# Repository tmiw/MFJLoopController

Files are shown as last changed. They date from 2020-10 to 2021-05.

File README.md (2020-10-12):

# MFJLoopController
A ESP8266-based remote controller for MFJ magnetic loops.

## Prerequisites

* WEMOS D1 mini Lite development board (or clone). [Example](https://www.amazon.com/gp/product/B081PX9YFV/ref=ppx_yo_dt_b_asin_title_o03_s00?ie=UTF8&psc=1)
* [Adafruit ADS1115 ADC](https://www.adafruit.com/product/1085)
* Arduino IDE with ESP boards and [LittleFS data uploader tool](https://arduino-esp8266.readthedocs.io/en/latest/filesystem.html#uploading-files-to-file-system) installed
* [MFJ Bias Tee](https://mfjenterprises.com/products/mfj-4116)
* [H bridge circuit](http://www.modularcircuits.com/blog/articles/h-bridge-secrets/h-bridges-the-basics/) to produce +/- 12V. Initial tests done with [LED based solid state relays](https://www.mouser.com/ProductDetail/IXYS-Integrated-Circuits/LCC120?qs=TzJIIqIe2vmIthf%252BEZpoaA%3D%3D) linked together in series to reduce required pin count to 2 (one for each direction).
* Isolated power supply (e.g. **NOT** connected to radio's ground). [This Mouser project](https://www.mouser.com/ProjectManager/ProjectDetail.aspx?AccessID=d2ae561f5a) seems to work reasonably well in initial testing to permit sharing 12V power supply with rest of shack (see datasheets for the TMR 9-1212 for required support circuitry to reduce possible RFI).
* Soon: SWR bridge capable of reading 100W and providing 3.3V max analog signals to the ADS1115 ([possible option](https://en.golb.be/automatic-magnetic-loop-tuner-swr-bridge/))

## Setup

1. Set configuration options (pins, Wi-Fi info, etc.) in config.h.
2. Build and upload software using Arduino IDE to device. *Note: the initial upload must be done using USB or UART; subsequent uploads can be done OTA.*
3. Upload filesystem using Tools > ESP8266 LittleFS Data Upload in the Arduino IDE.

## Usage

By default, the software uses DHCP to get an IP address. Simply go to its assigned IP address on port 80 in a Web browser and click on the desired tuning direction buttons; releasing the associated button results in tuning stop. Note that you're looking for maximum signal/noise for the initial pass at tuning; the eventual auto-tune feature will perform fine tuning for minimal SWR.

## To Do

* Auto-tuning
* SSL support?
* PCB combining all hardware and eliminating loose wires

## License

BSD 3-clause (TBD)

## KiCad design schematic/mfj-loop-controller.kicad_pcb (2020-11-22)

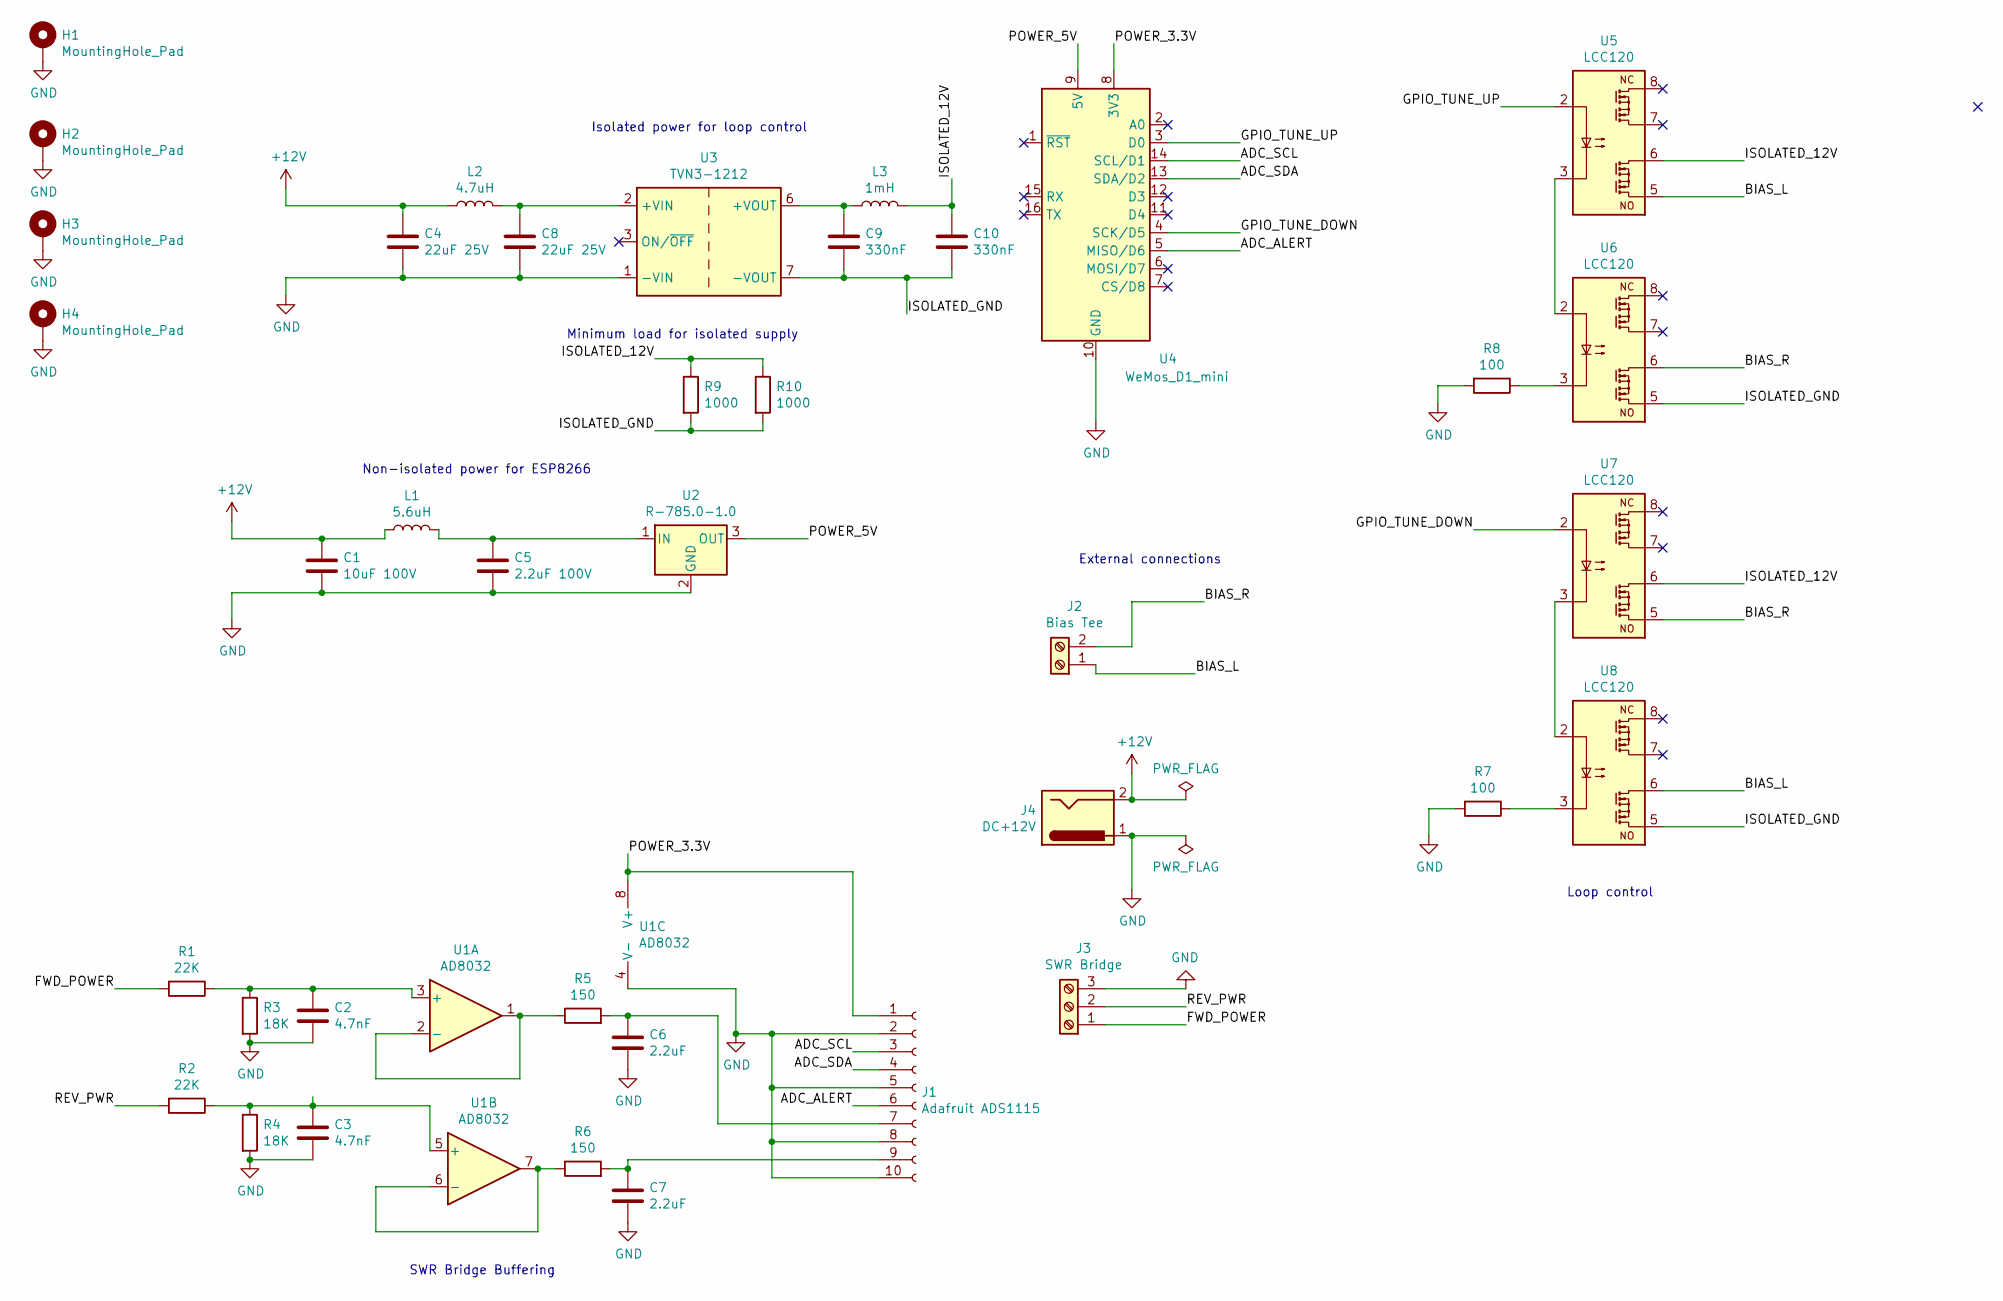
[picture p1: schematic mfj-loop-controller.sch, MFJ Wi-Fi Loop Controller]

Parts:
C1: 10uF 100V; C_Axial_L5.1mm_D3.1mm_P7.50mm_Horizontal
C2, C3: 4.7nF; C_Axial_L5.1mm_D3.1mm_P7.50mm_Horizontal
C4, C8: 22uF 25V; C_Axial_L5.1mm_D3.1mm_P7.50mm_Horizontal
C5: 2.2uF 100V; C_Axial_L5.1mm_D3.1mm_P7.50mm_Horizontal
C6, C7: 2.2uF; C_Axial_L5.1mm_D3.1mm_P7.50mm_Horizontal
C9, C10: 330nF; C_Axial_L5.1mm_D3.1mm_P7.50mm_Horizontal
H1, H2, H3, H4: MountingHole_Pad; MountingHole_3.2mm_M3_DIN965_Pad_TopBottom
J1: Adafruit ADS1115; PinHeader_1x10_P2.54mm_Vertical
J2: Bias Tee; TerminalBlock_bornier-2_P5.08mm
J3: SWR Bridge; TerminalBlock_bornier-3_P5.08mm
J4: DC+12V; BarrelJack_CUI_PJ-063AH_Horizontal_CircularHoles
L1: 5.6uH; L_Axial_L5.3mm_D2.2mm_P10.16mm_Horizontal_Vishay_IM-1
L2: 4.7uH; L_Axial_L5.3mm_D2.2mm_P10.16mm_Horizontal_Vishay_IM-1
L3: 1mH; L_Axial_L5.3mm_D2.2mm_P10.16mm_Horizontal_Vishay_IM-1
R1, R2: 22K; R_Axial_DIN0207_L6.3mm_D2.5mm_P10.16mm_Horizontal
R3, R4: 18K; R_Axial_DIN0207_L6.3mm_D2.5mm_P10.16mm_Horizontal
R5, R6: 150; R_Axial_DIN0207_L6.3mm_D2.5mm_P10.16mm_Horizontal
R7, R8: 100; R_Axial_DIN0207_L6.3mm_D2.5mm_P10.16mm_Horizontal
R9, R10: 1000; R_Axial_DIN0207_L6.3mm_D2.5mm_P10.16mm_Horizontal
U1: AD8032; DIP-8_W7.62mm_Socket
U2: R-785.0-1.0; Converter_DCDC_RECOM_R-78E-0.5_THT
U3: TVN3-1212; Converter_DCDC_TRACO_TMR-xxxx_THT
U4: WeMos_D1_mini; WEMOS_D1_mini_light
U5, U6, U7, U8: LCC120; DIP-8_W7.62mm_Socket

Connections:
+12V: C1.1, C4.1, J4.2, L1.1, L2.1
/ADC_ALERT: J1.6, U4.5 (MISO/D6)
/ADC_SCL: J1.3, U4.14 (SCL/D1)
/ADC_SDA: J1.4, U4.13 (SDA/D2)
/BIAS_L: J2.1, U5.5, U8.6
/BIAS_R: J2.2, U6.6, U7.5
/FWD_POWER: J3.1, R1.2
/GPIO_TUNE_DOWN: U4.4 (SCK/D5), U7.2
/GPIO_TUNE_UP: U4.3 (D0), U5.2
/ISOLATED_12V: C10.1, L3.2, R9.1, R10.1, U5.6, U7.6
/ISOLATED_GND: C9.2, C10.2, R9.2, R10.2, U3.7 (-VOUT), U6.5, U8.5
/POWER_3.3V: J1.1, U1.8 (V+), U4.8 (3V3)
/POWER_5V: U2.3 (OUT), U4.9 (5V)
/REV_PWR: J3.2, R2.2
GND: C1.2, C2.2, C3.2, C4.2, C5.2, C6.2, C7.2, C8.2, H1.1, H2.1, H3.1, H4.1, J1.2, J1.5, J1.8, J1.10, J3.3, J4.1, R3.2, R4.2, R7.2, R8.2, U1.4 (V-), U2.2 (GND), U3.1 (-VIN), U4.10 (GND)
unnamed: C2.1, R1.1, R3.1, U1.3 (+)
unnamed: C3.1, R2.1, R4.1, U1.5 (+)
unnamed: C5.1, L1.2, U2.1 (IN)
unnamed: C6.1, J1.7, R5.2
unnamed: C7.1, J1.9, R6.2
unnamed: C8.1, L2.2, U3.2 (+VIN)
unnamed: C9.1, L3.1, U3.6 (+VOUT)
unnamed: R5.1, U1.1, U1.2 (-)
unnamed: R6.1, U1.6 (-), U1.7
unnamed: R7.1, U8.3
unnamed: R8.1, U6.3
unnamed: U5.3, U6.2
unnamed: U7.3, U8.2

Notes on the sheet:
Minimum load for isolated supply
Isolated power for loop control
Non-isolated power for ESP8266
SWR Bridge Buffering
Loop control
External connections

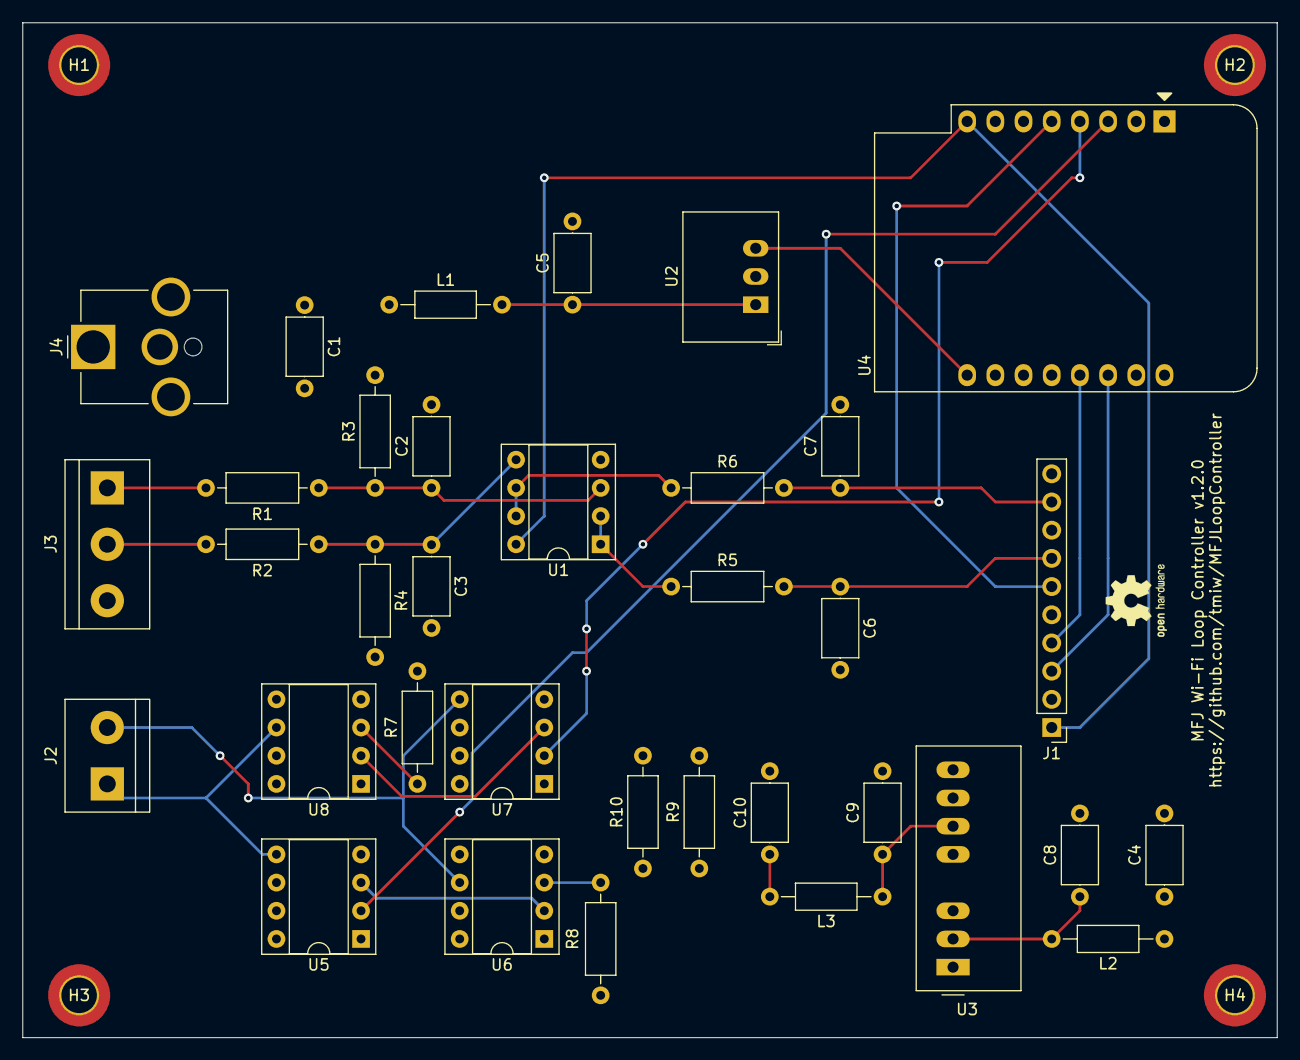
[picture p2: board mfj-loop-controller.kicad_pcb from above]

Board: 4 copper layers, 113.0 x 91.4 mm, 39 parts (0 on the bottom side), 28 nets.

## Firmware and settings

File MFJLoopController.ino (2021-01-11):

#include <ESP8266WiFi.h>
#include <WiFiClient.h>
#include <ArduinoOTA.h>
#include <LittleFS.h>
#include "WebServerController.h"
#include "CapacitorController.h"
#include "PowerMonitor.h"
#include "AutoTuneController.h"
#include "config.h"

CapacitorController capController;
PowerMonitor powerMonitor;
AutoTuneController autoTuneController(&capController, &powerMonitor);
WebServerController webServerController(&capController, &powerMonitor, &autoTuneController);

void checkWifi()
{
  if (WiFi.status() != WL_CONNECTED)
  {
    delay(1);
    
    WiFi.mode(WIFI_STA);
    WiFi.begin(STASSID, STAPSK);
  
    // Wait for connection
    while (WiFi.status() != WL_CONNECTED) {
      delay(500);
    }

    // Close all existing connections. If we disconnected, the connections are invalid anyway.
    webServerController.closeAll();
  }
}

void setup() {
  checkWifi();
  
  // FS init
  LittleFS.begin();
  
  capController.setup();
  powerMonitor.setup();
  webServerController.setup();
  autoTuneController.setup();
  
  // Set up OTA
  // Port defaults to 8266
  // ArduinoOTA.setPort(8266);

  // Hostname defaults to esp8266-[ChipID]
  // ArduinoOTA.setHostname("myesp8266");

  // No authentication by default
  // ArduinoOTA.setPassword("admin");

  ArduinoOTA.onStart([]() {
    // Stop what we're doing, if anything.
    capController.setDirection(CapacitorController::NONE);
    capController.setSpeed(CapacitorController::IDLE);
    capController.process();
    powerMonitor.enableAdc(false);

    // Wait a few ms for the ADC to stop signaling
    delay(5);
    
    String type;
    if (ArduinoOTA.getCommand() == U_FLASH) {
      type = "sketch";
    } else { // U_FS
      type = "filesystem";
      LittleFS.end();
    }
    
    //Serial.println("Start updating " + type);
  });
  ArduinoOTA.onEnd([]() {
    //Serial.println("\nEnd");

    // Remount FS
    LittleFS.begin();

    // Re-enable ADC
    powerMonitor.enableAdc(true);
  });
  ArduinoOTA.onProgress([](unsigned int progress, unsigned int total) {
    //Serial.printf("Progress: %u%%\r", (progress / (total / 100)));
  });
  ArduinoOTA.onError([](ota_error_t error) {
    //Serial.printf("Error[%u]: ", error);
    if (error == OTA_AUTH_ERROR) {
      //Serial.println("Auth Failed");
    } else if (error == OTA_BEGIN_ERROR) {
      //Serial.println("Begin Failed");
    } else if (error == OTA_CONNECT_ERROR) {
      //Serial.println("Connect Failed");
    } else if (error == OTA_RECEIVE_ERROR) {
      //Serial.println("Receive Failed");
    } else if (error == OTA_END_ERROR) {
      //Serial.println("End Failed");
    }
  });
  ArduinoOTA.begin();

}

void loop() 
{
  checkWifi();
  
  // Handle OTA
  ArduinoOTA.handle();

  capController.process();
  powerMonitor.process();
  autoTuneController.process();
  webServerController.process();
}

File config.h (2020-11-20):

#if !defined(CONFIG_H)
#define CONFIG_H

#include <ESP8266WiFi.h>

// Define STASSID (your wireless SSID) and STAPSK (your network's password)
// inside config-wifi.h. The below file is in .gitignore to prevent accidental check-in.
#include "config-wifi.h"

#define MDNS_NAME "mfj-loop"

#define TUNE_UP_PIN D0
#define TUNE_DOWN_PIN D5
#define ADC_INTERRUPT_PIN D6
#define TUNE_LED_PIN D4

// ADC gain
#define ADC_GAIN GAIN_ONE

// ADC channels
#define ADC_FWD_CH 0
#define ADC_REV_CH 2

// Fine tuning pulse time.
#define TUNE_FINE_PULSE_OFF_TIME_MS 150
#define TUNE_FINE_PULSE_ON_TIME_MS 18

// Slow tuning pulse time.
#define TUNE_SLOW_PULSE_OFF_TIME_MS 115
#define TUNE_SLOW_PULSE_ON_TIME_MS 36

// Fast tuning pulse time.
#define TUNE_FAST_PULSE_OFF_TIME_MS 0
#define TUNE_FAST_PULSE_ON_TIME_MS 36

// Minimum SWR difference (from prior reading) to wait for while in a wait state
// before proceeding to the next state.
#define AUTOTUNE_MIN_SWR_DIFF_IN_WAIT 0.1

// Length of time to move in the opposite direction before beginning auto-tune. This
// time is to ensure that we pass the dip while in fast mode (instead of stopping just
// short of it).
#define AUTOTUNE_BEGIN_TUNE_TIME_MS 2000

// VSWR "tuning complete" threshold (below after which we switch to slow tuning).
#define FAST_AUTOTUNE_COMPLETE_VSWR_THRESH ((double)2.0)

// VSWR "tuning complete" threshold (below after which we stop tuning).
#define SLOW_AUTOTUNE_COMPLETE_VSWR_THRESH ((double)2.0)

// Minimum wait time between tuning states to ensure capacitor remains stable enough
#define MIN_TUNE_WAIT_TIME_MS 100

// Maximum "good enough" SWR to exit tuning.
#define MAX_GOOD_SWR_END_TUNING ((double)1.5)

#endif // CONFIG_H

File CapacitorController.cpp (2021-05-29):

#include "CapacitorController.h"
#include "config.h"

CapacitorController::CapacitorController()
: direction_( NONE )
, speed_( IDLE )
, pwmState_( DISABLED )
, pwmPin_( 0 )
, pwmHighTimeMs_( 0 )
, pwmLowTimeMs_( 0 )
, pwmStateStartTime_( 0 )
{
  // empty
}

CapacitorController::~CapacitorController()
{
  // empty
}

void CapacitorController::setup()
{
  // Initialize both tuning pins to low.
  pinMode(TUNE_UP_PIN, OUTPUT);
  pinMode(TUNE_DOWN_PIN, OUTPUT);
  pinMode(TUNE_LED_PIN, OUTPUT);
  disableTuningPins_();
}

void CapacitorController::setDirection(Direction dir)
{
  // Force both tuning pins to low in the event of a direction change
  // to guarantee that the system doesn't short out.
  disableTuningPins_();
  pwmState_ = DISABLED;
  pwmStateStartTime_ = 0;
  
  // Set direction. Next call to process() will set the needed pin to high.
  direction_ = dir;
}

CapacitorController::Direction CapacitorController::getDirection() const
{
  return direction_;
}

void CapacitorController::setSpeed(CapacitorController::Speed speed)
{
  speed_ = speed;
}

CapacitorController::Speed CapacitorController::getSpeed() const
{
  return speed_;
}

bool CapacitorController::getOneShot() const
{
  return oneShot_;
}

void CapacitorController::setOneShot(bool val)
{
  oneShot_ = true;
}

void CapacitorController::process()
{
  // Set next PWM state.
  if (speed_ == IDLE)
  {
    disableTuningPins_();
    pwmState_ = DISABLED;
  }
  else if (speed_ == FINE)
  {
    setPwmSettings(direction_ == DOWN ? TUNE_DOWN_PIN : TUNE_UP_PIN, TUNE_FINE_PULSE_ON_TIME_MS, TUNE_FINE_PULSE_OFF_TIME_MS);
  }
  else if (speed_ == SLOW)
  {
    setPwmSettings(direction_ == DOWN ? TUNE_DOWN_PIN : TUNE_UP_PIN, TUNE_SLOW_PULSE_ON_TIME_MS, TUNE_SLOW_PULSE_OFF_TIME_MS);
  }
  else if (speed_ == FAST)
  {
    setPwmSettings(direction_ == DOWN ? TUNE_DOWN_PIN : TUNE_UP_PIN, TUNE_FAST_PULSE_ON_TIME_MS, TUNE_FAST_PULSE_OFF_TIME_MS);
  }

  // PWM handling
  if (pwmState_ != DISABLED)
  {
    auto currentTime = millis();
    if (pwmStateStartTime_ == 0) pwmStateStartTime_ = currentTime;
    
    switch (pwmState_)
    {
      case PWM_HIGH:
        //GPOC = (1 << TUNE_LED_PIN);
        //GPOS = (1 << pwmPin_);
        digitalWrite(TUNE_LED_PIN, LOW);
        digitalWrite(pwmPin_, HIGH);

        if ((currentTime - pwmStateStartTime_) >= pwmHighTimeMs_)
        {
          if (pwmLowTimeMs_ > 0)
          {
            disableTuningPins_();
            pwmState_ = PWM_LOW;
          }
          pwmStateStartTime_ = 0; // Will reset to the current time on next loop
        }
        break;
      case PWM_LOW:
        //GPOS = (1 << TUNE_LED_PIN);
        //GPOC = (1 << pwmPin_);
        digitalWrite(TUNE_LED_PIN, HIGH);
        digitalWrite(pwmPin_, LOW);

        if ((currentTime - pwmStateStartTime_) >= pwmLowTimeMs_)
        {
          disableTuningPins_();
          pwmState_ = oneShot_ ? DISABLED : PWM_HIGH;
          pwmStateStartTime_ = 0; // Will reset to the current time on next loop

          if (oneShot_) 
          {
            oneShot_ = false;
            setSpeed(IDLE);
            setDirection(NONE);
          }
        }
        break;
    }
  }
}

void CapacitorController::disableTuningPins_()
{
  // Directly manipulating the needed registers is far faster than using
  // digitalWrite() and thus will reduce the overshoot when switching directions.
  //GPOC = (1 << TUNE_UP_PIN) | (1 << TUNE_DOWN_PIN);
  //GPOS = (1 << TUNE_LED_PIN);
  digitalWrite(TUNE_UP_PIN, LOW);
  digitalWrite(TUNE_DOWN_PIN, LOW);
  digitalWrite(TUNE_LED_PIN, HIGH);
}

void CapacitorController::forceStop()
{
  disableTuningPins_();
  speed_ = IDLE;
  direction_ = NONE;
  pwmState_ = DISABLED;
}

void CapacitorController::setPwmSettings(int pin, int highTimeMs, int lowTimeMs)
{
  if (pwmState_ == DISABLED || pin != pwmPin_ || highTimeMs != pwmHighTimeMs_ || lowTimeMs != pwmLowTimeMs_)
  {
    disableTuningPins_();
    pwmPin_ = pin;
    pwmHighTimeMs_ = highTimeMs;
    pwmLowTimeMs_ = lowTimeMs;
    pwmState_ = PWM_HIGH;
    pwmStateStartTime_ = 0; // will reset on next loop
  }
}

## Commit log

2020-10-12 Add files from initial prototype.
2020-10-14 Use preliminary equations for forward/reverse power.
    [PowerMonitor.cpp]
2020-10-18 Initial schematic and PCB for tuner board.
    [mfj-loop-controller.kicad_pcb, mfj-loop-controller.sch]
2020-10-18 Update PCB markings and version info.
    [mfj-loop-controller.kicad_pcb, mfj-loop-controller.sch]
2020-10-24 Adjust equation for FW power based on new numbers from PCB.
2020-10-24 Have browser control slow tune and not device to enable easier control.
2020-10-25 Blink ESP board LED during tuning for debugging.
2020-10-25 Use same ADC->watts equation for both fwd/rev power.
2020-10-27 Send large pulse on changing directions to overcome capacitor inertia.
2020-10-27 Autotune/ADC experiments.
2020-10-27 Use actual working IIR filter and update SWR calculation.
2020-10-31 Update schematic and PCB to v1.1.0:
    1. Shrink board footprint to ~4x3" for ease of mounting/EMI compliance.
    2. Add mounting holes to corners.
    3. Add GND/+12V flood fill layers for EMI compliance/routing.
    4. Increase size of R/C/L component footprints for ease of assembly.
    5. Add route for ADC alert pin to ESP82xx board.
    6. Add routes for ADC analog negative pins to ground.
    7. Add buffer op-amp + supporting RC filters in front of ADC.
    8. Add Open Hardware logo to silkscreen.
    [mfj-loop-controller.kicad_pcb, mfj-loop-controller.sch]
2020-10-31 Update design rules.
    [mfj-loop-controller.kicad_pcb, mfj-loop-controller.sch]
2020-11-01 Minor tweaks to PCB.
    [mfj-loop-controller.kicad_pcb]
2020-11-04 Use interrupts to read current ADC values more quickly.
2020-11-06 Reliable loop auto-tuning in slow mode + re-calibration of power meter
2020-11-12 Major changes to firmware:
    1. Use WebSockets for commands and status updates (to allow for smoother UI).
    2. Use timings corresponding to original MFJ loop tuner control box.
    3. Reenable fast tuning step for autotuning (in progress).
    4. Add delay states between auto-tuning steps to allow for SWR to stabilize.
    [CapacitorController.cpp, config.h]
2020-11-17 Rotate power jack 180 degrees on PCB.
    [mfj-loop-controller.kicad_pcb]
2020-11-17 Use fabs in order to fix bugs with SWR reporting.
    [CapacitorController.cpp, PowerMonitor.cpp, PowerMonitor.h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]
2020-11-18 Add minimum load to 12V isolated supply to reduce tuning noise.
    [mfj-loop-controller.kicad_pcb, mfj-loop-controller.sch]
2020-11-19 Switch JSON status output to using Arduino JSON library.
2020-11-19 Request initial status from the board when connecting the WEbSocket.
2020-11-20 Fixed bugs in autotuning.
    [config.h]
2020-11-22 Hardware version 1.2.0:
    1. Change 12V isolated supply to "low ripple/noise" version (TVN 3-1212).
    2. Add/update required filtering to reflect TVN 3-1212 and to further reduce ripple.
    3. Reroute isolated section to shorten traces and to use isolated power/ground planes (EMI reduction).
    4. Add optional (?) "minimum load" resistors for use if TVN 3-1212 requires them for proper operation while idle/slow tuning.
    [mfj-loop-controller.kicad_pcb, mfj-loop-controller.sch]
2021-04-17 Fix issue with HTML causing Chrome/device to eventually lock up.
